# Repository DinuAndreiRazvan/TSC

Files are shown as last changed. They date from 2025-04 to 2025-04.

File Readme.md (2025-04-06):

# eBook Project - Autodesk Fusion 360 

## Images

*Complete View*
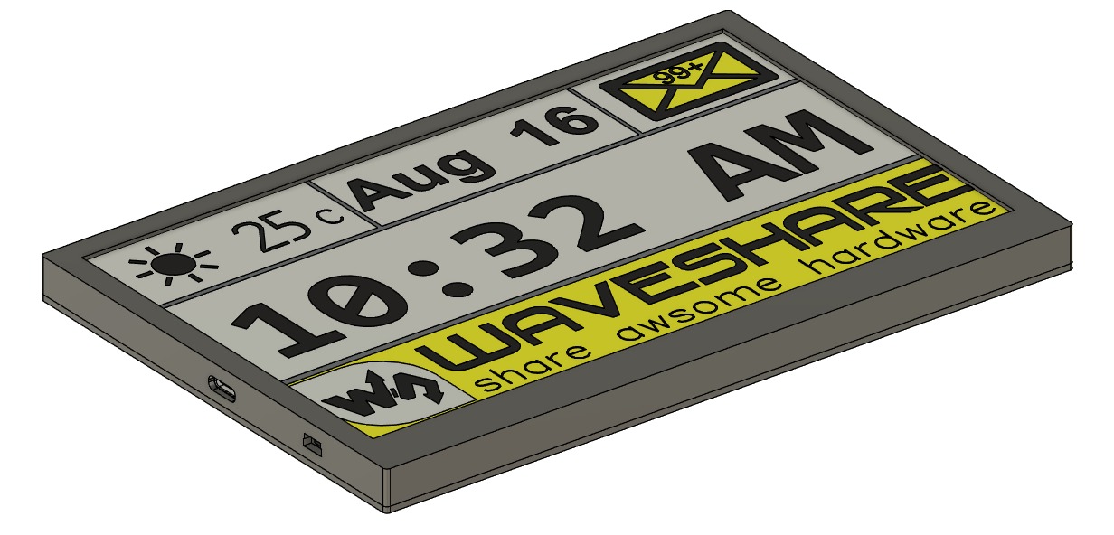
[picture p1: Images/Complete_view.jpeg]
Complete View


*Exploded View*
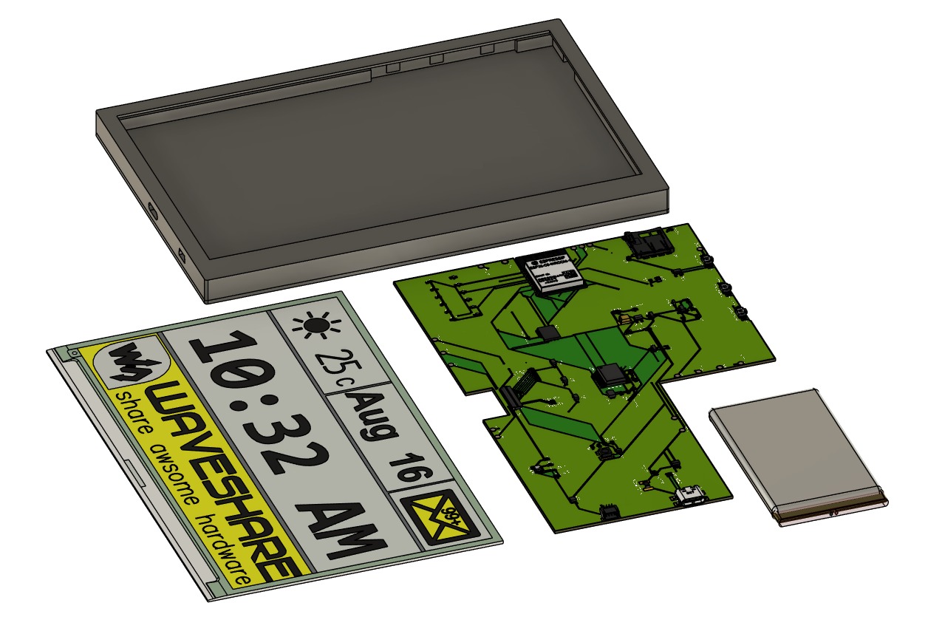
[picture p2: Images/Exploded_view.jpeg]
Exploded View


*PCB*
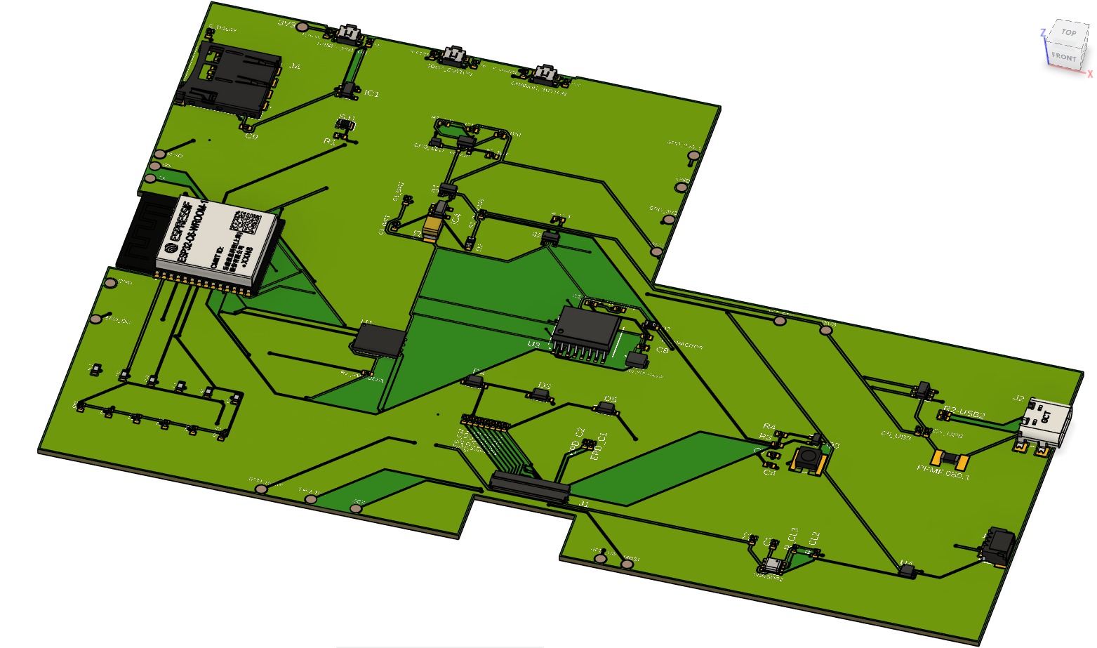
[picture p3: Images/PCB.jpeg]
PCB


## Block Diagram

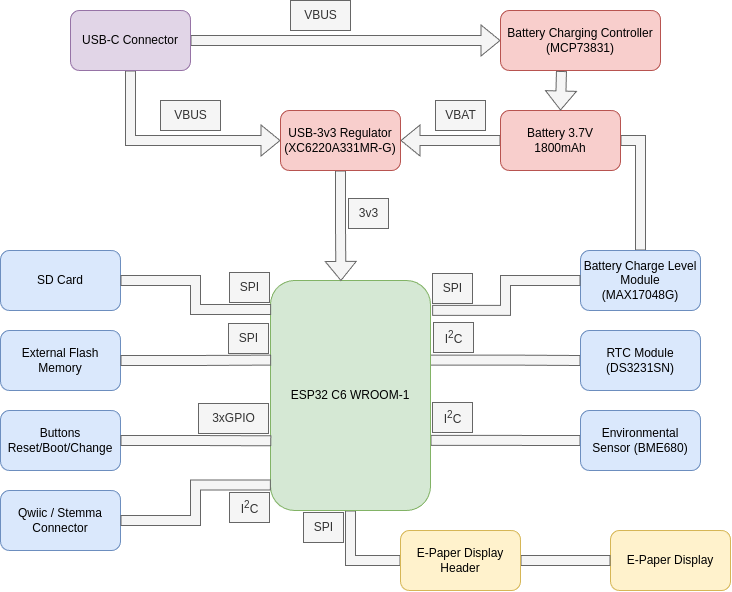
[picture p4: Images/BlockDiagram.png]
Block Diagram


## Bill of Materials

| Component | Description | Datasheet | Shop |
|---|---|---|---|
| ESP32-C6-WROOM-1-N8 | Wi-Fi, BLE, Zigbee SoC Module | [Datasheet](https://www.espressif.com/sites/default/files/documentation/esp32-c6-wroom-1_wroom-1u_datasheet_en.pdf) | [Shop](https://eu.mouser.com/ProductDetail/Espressif-Systems/ESP32-C6-WROOM-1U-N8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) |
| MCP73831 | Li-Po Battery Charging Controller | [Datasheet](https://eu.mouser.com/datasheet/2/268/MCP73831_Family_Data_Sheet_DS20001984H-3441711.pdf) | [Shop](https://eu.mouser.com/ProductDetail/Microchip-Technology/MCP73831T-2ACI-OT?qs=yUQqVecv4qvbBQBGbHx0Mw%3D%3D) |
| XC6220A331MR-G | LDO Voltage Regulator | [Datasheet](https://eu.mouser.com/datasheet/2/760/xc6220-3371556.pdf) | [Shop](https://eu.mouser.com/ProductDetail/Torex-Semiconductor/XC6220A331MR-G?qs=AsjdqWjXhJ8ZSWznL1J0gg%3D%3D) |
| BME680 | Environmental Sensor | [Datasheet](https://eu.mouser.com/datasheet/2/783/BST_BME680_DS001-1509608.pdf) | [Shop](https://eu.mouser.com/ProductDetail/Bosch-Sensortec/BME680?qs=v271MhAjFHjo0yA%2FC4OnDQ%3D%3D) |
| DS3231SN | Real-Time Clock | [Datasheet](https://eu.mouser.com/datasheet/2/609/DS3231-3421123.pdf) | [Shop](https://eu.mouser.com/ProductDetail/Analog-Devices-Maxim-Integrated/DS3231SN?qs=1eQvB6Dk1vhUlr8%2FOrV0Fw%3D%3D) |
| MAX17048G+T10 | Battery Fuel Gauge | [Datasheet](https://eu.mouser.com/datasheet/2/609/MAX17048_MAX17049-3469099.pdf) | [Shop](https://eu.mouser.com/ProductDetail/Analog-Devices-Maxim-Integrated/MAX17048G%2bT10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) |
| W25Q512JVEIQ | 512Mb Flash Memory | [Datasheet](https://eu.mouser.com/datasheet/2/949/Winbond_W25Q512JV_Datasheet-3240039.pdf) | [Shop](https://eu.mouser.com/ProductDetail/Winbond/W25Q512JVEIQ?qs=l7cgNqFNU1jw6svr3at6tA%3D%3D) |
| USB4110-GF-A | USB Type-C Connector | [Datasheet](https://eu.mouser.com/datasheet/2/837/GCT_USB4110_Product_Drawing___20k_cycles-3455479.pdf) | [Shop](https://eu.mouser.com/ProductDetail/GCT/USB4110-GF-A?qs=KUoIvG%2F9IlYiZvIXQjyJeA%3D%3D) |
| 112A-TAAR-R03 | Micro SD Card Connector | [Datasheet](https://www.attend.com.tw/data/download/file/112A-TAAR-R03_Spec.pdf) | [Shop](https://www.tme.eu/ro/details/mcc-sdmicro/conectori-pentru-cartele/attend/112a-taar-r03/) |
| SI1308EDL-T1-GE3 | N-Channel MOSFET | [Datasheet](https://www.vishay.com/docs/63399/si1308edl.pdf) | [Shop](https://eu.mouser.com/ProductDetail/Vishay-Semiconductors/SI1308EDL-T1-GE3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) |
| DMG2305UX-7 | P-Channel MOSFET | [Datasheet](https://www.diodes.com/assets/Datasheets/DMG2305UX.pdf) | [Shop](https://eu.mouser.com/ProductDetail/Diodes-Incorporated/DMG2305UX-7?qs=L1DZKBg7t5F%2FNBHrjfxC%252Bg%3D%3D) |
| USBLC6-2SC6Y | USB ESD Protection | [Datasheet](https://eu.mouser.com/datasheet/2/389/usblc6_2sc6y-1852505.pdf) | [Shop](https://eu.mouser.com/ProductDetail/STMicroelectronics/USBLC6-2SC6Y?qs=gNDSiZmRJS%2FOgDexvXkdow%3D%3D) |
| CPH3225 | 11mF Supercapacitor | [Datasheet](https://eu.mouser.com/datasheet/2/360/Seiko_Instruments_MicroBattery_E_20230330_2024Jan_-3561061.pdf) | [Shop](https://eu.mouser.com/ProductDetail/Seiko-Semiconductors/CPH3225A?qs=3etwrb1wR%252BhUOph6lAO7eg%3D%3D) |
| Waveshare Display | 7.5" E-Ink | [Datasheet](https://files.waveshare.com/upload/6/60/7.5inch_e-Paper_V2_Specification.pdf) | [Shop](https://www.waveshare.com/7.5inch-e-paper-hat.htm) |
| Cellevia Battery | Polymer Lithium-Ion | [Datasheet](https://www.tme.eu/Document/e0683d8c34e6d878124489f71bffb6ee/cel0014.pdf) | [Shop](https://www.emag.ro/acumulator-litiu-polymer-cellevia-3-7v-1800mah-accu-lp364778-c/pd/DVCNMRBBM/) | 
| MBR0530 | Schottky Diode | [Datasheet](https://www.onsemi.com/download/data-sheet/pdf/mbr0530t1-d.pdf) | [Shop](https://eu.mouser.com/ProductDetail/onsemi/MBR0530T3G?qs=3JMERSakebpEmdUS6GetdQ%3D%3D) |
| CC0402 | Capacitor | [Datasheet](https://eu.mouser.com/datasheet/2/447/upy_gphc_x5r_4v_to_50v-3461255.pdf) | [Shop](https://eu.mouser.com/ProductDetail/YAGEO/CC0402KRX5R6BB105?qs=BKNoF%2F0xMNu0TvpE6ze2Iw%3D%3D) | 
| RR0402 | Resistor | [Datasheet](https://www.vishay.com/docs/28952/mcs0402at-mct0603at-mcu0805at-mca1206at.pdf) | [Shop](https://eu.mouser.com/ProductDetail/Vishay-Beyschlag/MCS0402MD1002BE100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) |

## Hardware Functionality

### Power Management
The device can be powered in multiple ways:
- **USB Power**: Through USB-C connector (USB4110-GF-A) with ESD protection (USBLC6-2SC6Y)
- **LiPo Battery**: Charged via MCP73831 controller with status LED
- **Supercapacitor Backup**: CPH3225A for maintaining functionality during power transitions

The power path includes:
- XC6220A331MR-G LDO provides stable 3.3V to the system
- MAX17048G+T10 monitors battery capacity
- P-channel MOSFETs (DMG2305UX-7) for power path selection
- Schottky diodes (MBR0530) for reverse voltage protection

### Processing & Memory
- **ESP32-C6-WROOM-1-N8**: Main microcontroller with Wi-Fi 6, Bluetooth 5, and Zigbee 3.0 capabilities
- **W25Q512JVEIQ**: 512Mb external SPI flash memory for data storage
- **SD Card Slot**: For user data storage and expansion

### Display System
- 7.5 inch E-Paper display interfaced via SPI
- Multiple capacitors for drive stability and voltage management

### Sensors
- **BME680/BME688**: I²C environmental sensor measuring:
    - Temperature: -40 to +85°C
    - Humidity: 0-100% RH
    - Pressure: 300-1100 hPa
    - Air Quality (gas resistance)
- **DS3231SN**: Highly accurate I²C real-time clock with temperature compensation

### Connectivity
- **USB-C**: For programming, data transfer, and charging
- **Qwiic/STEMMA QT**: I²C connector for external sensors/accessories
- **SD Card**: For data storage expansion

### User Interface
- **Reset Button**: For restarting the system
- **Boot Button**: For entering bootloader mode
- **Change Button**: For user interaction with the displayed content

## ESP32-C6 Pinout Configuration

| ESP32-C6 Pin | Function | Connected Component | Interface |
|---|---|---|---|
| EN | Reset | RESET_BUTTON | Digital Input |
| GPIO 0 | INT_RTC | DS3231SN | Interrupt |
| GPIO 1 | 32 khz | DS3231SN | Clock Output |
| GPIO 2 | MISO | SPI Bus | SPI |
| GPIO 3 | E-Paper BUSY | E-Paper Display | Digital Input |
| GPIO 4 | SD Card CS | SD Card Slot | SPI |
| GPIO 5 | E-Paper DC | E-Paper Display | Digital Output |
| GPIO 6 | SCK - Clock | SPI Bus | SPI |
| GPIO 7 | MOSI | SPI Bus | SPI |
| GPIO 9 | IO/Boot | BOOT_BUTTON | Digital Input |
| GPIO 10 | E-Paper CS | E-Paper Display | SPI |
| GPIO 11 | Flash CS | W25Q512JVEIQ | SPI |
| GPIO 12 | USB_D- | USB Interface | USB |
| GPIO 13 | USB_D+ | USB Interface | USB |
| GPIO 15 | IO/Change | CHANGE_BUTTON | Digital Input |
| GPIO 16 | TX | USB-to-Serial | UART |
| GPIO 17 | RX | USB-to-Serial | UART |
| GPIO 18 | RTC Reset | DS3231SN | Digital Output |
| GPIO 19 | I2C_PW | I²C Power Control | Digital Output |
| GPIO 20 | EPD_3V3_C | E-Paper Display Power | Power Control |
| GPIO 21 | SDA | I²C Bus (BME680, RTC) | I²C |
| GPIO 22 | SCL | I²C Bus (BME680, RTC) | I²C |
| GPIO 23 | E-Paper RESET | E-Paper Display | Digital Output |

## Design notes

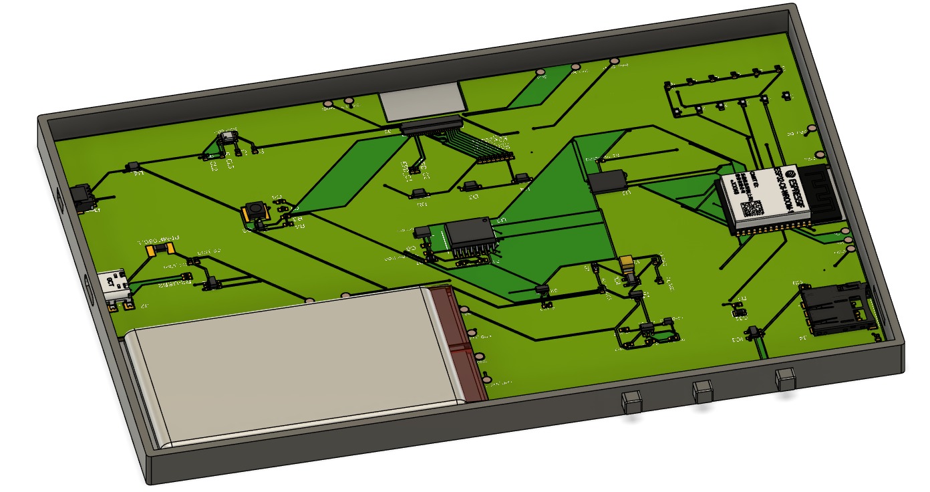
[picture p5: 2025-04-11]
Images/Open_view.jpeg

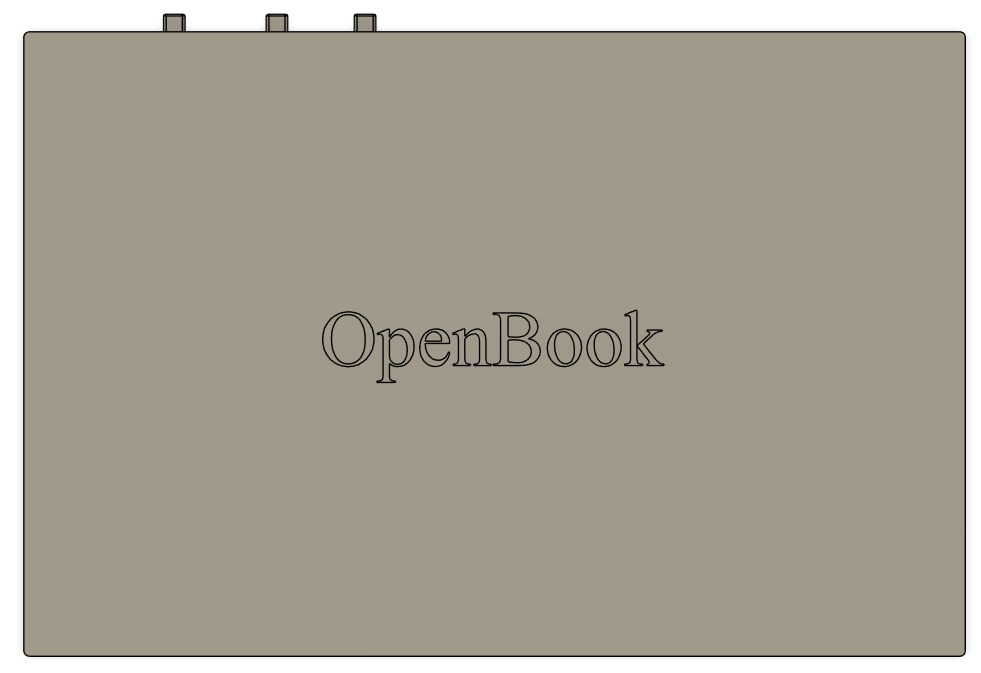
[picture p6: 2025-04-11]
Images/Back_view.jpeg

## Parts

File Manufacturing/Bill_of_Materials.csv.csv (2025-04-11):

Qty | Value | Device | Package | Parts | Description | ARROW_PART_NUMBER | ARROW_PRICE-STOCK | AVAILABILITY | CENTROID_NOT_SPECIFIED | CHECK_PRICES | COPYRIGHT | DATASHEET | DESCRIPTION | DIGIKEY_DESCRIPTION | DIGIKEY_PART_NUMBER | HEIGHT | LEAD_FREE | MANUFACTURER_NAME | MANUFACTURER_PART_NUMBER | MF | MFR_NAME | MOUSER_PART_NUMBER | MOUSER_PRICE-STOCK | MOUSER_TESTING_PART_NUMBER | MOUSER_TESTING_PRICE-STOCK | MP | MPN | PACKAGE | POPULARITY | PREFIX | PRICE | PROD_ID | PURCHASE-URL | ROHS | SNAPEDA_LINK | SPICEMODEL | SPICEPREFIX | TEMPERATURE_RANGE_HIGH | TEMPERATURE_RANGE_LOW | TP_SIGNAL_NAME | VALUE
1 |  | ADAFRUIT_LEDCHIP-LED0603 | ADAFRUIT_CHIP-LED0603 | CHG_LED | LED
1 |  | SJ | SJ | SJ1 | SMD solder JUMPER |  |  |  |  |  |  |  |  |  |  |  |  |  |  |  |  |  |  |  |  |  |  |  | 3
1 | 0.47 | ESP32_WROVER_EAGLE-LTSPICE_RR0402 | ESP32_WROVER_EAGLE-LTSPICE_R0402 | R3 | RESISTOR, European symbol |  |  |  |  |  |  |  |  |  |  |  |  |  |  |  |  |  |  |  |  |  |  |  |  |  |  |  |  |  |  | NONE | R
2 | 100k | ESP32_WROVER_EAGLE-LTSPICE_RR0402 | ESP32_WROVER_EAGLE-LTSPICE_R0402 | R1_PWRUSB, R1_PWRUSB1 | RESISTOR, European symbol |  |  |  |  |  |  |  |  |  |  |  |  |  |  |  |  |  |  |  |  |  |  |  |  |  |  |  |  |  |  | NONE | R
6 | 100nF | EAGLE-LTSPICE_CC0402 | EAGLE-LTSPICE_C0402 | C1, C2, C6, C8, C10, C_DELAY | CAPACITOR, European symbol |  |  |  |  |  |  |  |  |  |  |  |  |  |  |  |  |  |  |  |  |  |  |  |  |  |  |  |  |  |  | NONE | C
2 | 100nF | ESP32_WROVER_EAGLE-LTSPICE_CC0402 | ESP32_WROVER_EAGLE-LTSPICE_C0402 | C4_USB, C9 | CAPACITOR, European symbol |  |  |  |  |  |  |  |  |  |  |  |  |  |  |  |  |  |  |  |  |  |  |  |  |  |  |  |  |  |  | NONE | C
1 | 100uF TANT | RCL_CPOL-EUCT3528 | RCL_CT3528 | C3 | POLARIZED CAPACITOR, European symbol |  |  |  |  |  |  |  |  |  |  |  |  |  |  |  |  |  |  |  |  |  |  |  | 0 |  |  |  |  |  |  |  | C
15 | 10k | ESP32_WROVER_EAGLE-LTSPICE_RR0402 | ESP32_WROVER_EAGLE-LTSPICE_R0402 | R1_PINH1, R2_PINH1, R4, R5, R6, R7, R8, R9, R10, R_BOOT, R_CHANGE, R_CL1, R_CL2, R_CL3, R_RESET | RESISTOR, European symbol |  |  |  |  |  |  |  |  |  |  |  |  |  |  |  |  |  |  |  |  |  |  |  |  |  |  |  |  |  |  | NONE | R
1 | 10uF | EAGLE-LTSPICE_CC0402 | EAGLE-LTSPICE_C0402 | C7 | CAPACITOR, European symbol |  |  |  |  |  |  |  |  |  |  |  |  |  |  |  |  |  |  |  |  |  |  |  |  |  |  |  |  |  |  | NONE | C
1 | 112A-TAAR-R03_ATTEND | 112A-TAAR-R03_ATTEND | 112ATAARR03ATTEND | J4 | Micro SD Card Socket, Push-Push Type, Top Mount, SMT, H=1.83mm, 10u |  |  |  |  |  |  |  | Micro SD Card Socket | Push-Push Type | Top Mount | SMT | H=1.83mm | 10u |  |  | 1.9mm |  | ATTEND | 112A-TAAR-R03 ATTEND
1 | 15 | ESP32_WROVER_EAGLE-LTSPICE_RR0402 | ESP32_WROVER_EAGLE-LTSPICE_R0402 | R_CAPACITOR | RESISTOR, European symbol |  |  |  |  |  |  |  |  |  |  |  |  |  |  |  |  |  |  |  |  |  |  |  |  |  |  |  |  |  |  | NONE | R
1 | 1uF | EAGLE-LTSPICE_CC0402 | EAGLE-LTSPICE_C0402 | C5 | CAPACITOR, European symbol |  |  |  |  |  |  |  |  |  |  |  |  |  |  |  |  |  |  |  |  |  |  |  |  |  |  |  |  |  |  | NONE | C
10 | 1uF/50V | EAGLE-LTSPICE_CC0402 | EAGLE-LTSPICE_C0402 | EPD_C1, EPD_C2, EPD_C5, EPD_C6, EPD_C7, EPD_C8, EPD_C9, EPD_C10, EPD_C11, EPD_C12 | CAPACITOR, European symbol |  |  |  |  |  |  |  |  |  |  |  |  |  |  |  |  |  |  |  |  |  |  |  |  |  |  |  |  |  |  | NONE | C
1 | 2.2 | ESP32_WROVER_EAGLE-LTSPICE_RR0402 | ESP32_WROVER_EAGLE-LTSPICE_R0402 | R1 | RESISTOR, European symbol |  |  |  |  |  |  |  |  |  |  |  |  |  |  |  |  |  |  |  |  |  |  |  |  |  |  |  |  |  |  | NONE | R
1 | 200 | ESP32_WROVER_EAGLE-LTSPICE_RR0402 | ESP32_WROVER_EAGLE-LTSPICE_R0402 | R1_BAT | RESISTOR, European symbol |  |  |  |  |  |  |  |  |  |  |  |  |  |  |  |  |  |  |  |  |  |  |  |  |  |  |  |  |  |  | NONE | R
2 | 20V/4.2A/52mO/1.4W | ESP32_WROVER_SPARKFUN-DISCRETESEMI_MOSFET_PCH-DMG2305UX-7 | ESP32_WROVER_SPARKFUN-DISCRETESEMI_SOT23-3 | Q1, Q2 | P-channel MOSFETs |  |  |  |  |  |  |  |  |  |  |  |  |  |  |  |  |  |  |  |  |  |  |  |  |  |  | TRAN-14388 |  |  |  |  |  |  |  |  | 20V/4.2A/52mO/1.4W
1 | 2k | ESP32_WROVER_EAGLE-LTSPICE_RR0402 | ESP32_WROVER_EAGLE-LTSPICE_R0402 | R2_BAT | RESISTOR, European symbol |  |  |  |  |  |  |  |  |  |  |  |  |  |  |  |  |  |  |  |  |  |  |  |  |  |  |  |  |  |  | NONE | R
4 | 4.7uF | EAGLE-LTSPICE_CC0402 | EAGLE-LTSPICE_C0402 | C1_BAT, C1_BAT1, C1_BAT2, C2_BAT | CAPACITOR, European symbol |  |  |  |  |  |  |  |  |  |  |  |  |  |  |  |  |  |  |  |  |  |  |  |  |  |  |  |  |  |  | NONE | C
1 | 4.7uF | ESP32_WROVER_EAGLE-LTSPICE_CC0402 | ESP32_WROVER_EAGLE-LTSPICE_C0402 | C5_USB | CAPACITOR, European symbol |  |  |  |  |  |  |  |  |  |  |  |  |  |  |  |  |  |  |  |  |  |  |  |  |  |  |  |  |  |  | NONE | C
1 | 4.7uF/25V | EAGLE-LTSPICE_CC0402 | EAGLE-LTSPICE_C0402 | C4 | CAPACITOR, European symbol |  |  |  |  |  |  |  |  |  |  |  |  |  |  |  |  |  |  |  |  |  |  |  |  |  |  |  |  |  |  | NONE | C
2 | 5k1 | ESP32_WROVER_EAGLE-LTSPICE_RR0402 | ESP32_WROVER_EAGLE-LTSPICE_R0402 | R2-USB1, R2-USB2 | RESISTOR, European symbol |  |  |  |  |  |  |  |  |  |  |  |  |  |  |  |  |  |  |  |  |  |  |  |  |  |  |  |  |  |  | NONE | R
1 | 744043680IND_4828-WE-TPC_WRE | 744043680IND_4828-WE-TPC_WRE | IND_4828-WE-TPC_WRE | L1 |  |  |  |  |  |  | Copyright (C) 2024 Ultra Librarian. All rights reserved. |  |  |  |  |  |  |  | 744043680 |  | Wurth Electronics
1 | BD5229G-TR | BD5229G-TR | SOT95P280X125-5N | IC1 | Voltage Detector with Adjustable Delay Time: CMOS processes are utilized to develop high precision, low current consumption CMOS reset ICs that allow arbitrary setting of the delay time. The extensive lineup includes both Nch Open Drain and CMOS output types in a wide range of detection voltages (from 2.3V to 6.0V, in 0.1V steps), enabling selection of the ideal solution based on customer requirements. In addition, the entire series is of course both lead-free and RoHS-compliant. |  |  |  |  |  |  |  | Voltage Detector with Adjustable Delay Time: CMOS processes are utilized to develop high precision | low current consumption CMOS reset ICs that allow arbitrary setting of the delay time. The extensive lineup includes both Nch Open Drain and CMOS output types in a wide range of detection voltages (from 2.3V to 6.0V | in 0.1V steps) | enabling selection of the ideal solution based on customer requirements. In addition | the entire series is of course both lead-free and RoHS-compliant. |  |  | 1.25mm |  | ROHM Semiconductor | BD5229G-TR |  |  | 755-BD5229G-TR | https://www.mouser.co.uk/ProductDetail/ROHM-Semiconductor/BD5229G-TR?qs=4kLU8WoGk0vvnhrrYwdszw%3D%3D
3 | BUTTON_CUSYOMV1 | BUTTON_CUSYOMV1 | MYBUTTON | BOOT_BUTTON, CHANGE_BUTTON, RESET_BUTTON
1 | CPH3225A | CPH3225A | CAPCP3225X100N | C10_SUPERCAP | Cap 0.011F 3.3V 1210 Flat Check availability |  |  | Not in stock |  | https://www.snapeda.com/parts/CPH3225A/Seiko+Instruments/view-part/?ref=eda |  |  | 11 mF (EDLC) Supercapacitor 3.3 V 1210 (3225 Metric) - - |  |  |  |  |  |  | Seiko Instruments |  |  |  |  |  | CPH3225A |  | 1210 Seiko |  |  | None |  | https://www.snapeda.com/api/url_track_click_mouser/?unipart_id=562593&manufacturer=Seiko Instruments&part_name=CPH3225A&search_term=None |  | https://www.snapeda.com/parts/CPH3225A/Seiko+Instruments/view-part/?ref=snap
1 | DS3231SN# | DS3231SN# | SOIC127P1032X265-16N | U3 | Real Time Clock Serial 16-Pin SOIC W T/R Check availability |  |  | In Stock |  | https://www.snapeda.com/parts/DS3231SN%23/Analog+Devices/view-part/?ref=eda |  |  | Extremely Accurate I²C-Integrated RTC/TCXO/Crystal |  |  |  |  |  |  | Analog Devices |  |  |  |  |  | DS3231SN# |  | SOIC-16 Maxim |  |  | None |  | https://www.snapeda.com/api/url_track_click_mouser/?unipart_id=99048&manufacturer=Analog Devices&part_name=DS3231SN#&search_term=None |  | https://www.snapeda.com/parts/DS3231SN%23/Analog+Devices/view-part/?ref=snap
1 | ESP32-C6-WROOM-1-N8 | ESP32-C6-WROOM-1-N8 | XCVR_ESP32-C6-WROOM-1-N8 | U2 | Check availability |  |  | In Stock |  | https://www.snapeda.com/parts/ESP32-C6-WROOM-1-N8/Espressif+Systems/view-part/?ref=eda |  |  | Multiprotocol Modules ESP32-C6 module | Wi-Fi 6 in 2.4 GHz band | Bluetooth 5 | Zigbee 3.0 and Thread. ESP34-WROOM Compatible - ENGINEERING SAMPLE |  |  |  |  |  |  | Espressif Systems |  |  |  |  |  | ESP32-C6-WROOM-1-N8 |  | None |  |  | None |  |  |  | https://www.snapeda.com/parts/ESP32-C6-WROOM-1-N8/Espressif+Systems/view-part/?ref=snap
1 | ESP32C6_VARISTORCN1812 | ESP32C6_VARISTORCN1812 | ESP32C6_VARISTOR_CT/CN1812 | PFMF.050.1 | VARISTOR |  |  |  |  |  |  |  |  |  |  |  |  |  |  |  |  |  |  |  |  |  |  |  | 0
2 | ESP32_WROVER_AVX---SD0805S020S1R0_AVX_SD0805S020S1R0_0_0AVX_SD0805S020S1R0_0_0 | ESP32_WROVER_AVX---SD0805S020S1R0_AVX_SD0805S020S1R0_0_0AVX_SD0805S020S1R0_0_0 | ESP32_WROVER_AVX---SD0805S020S1R0_AVX_SD0805S020S1R0_0 | D2, D7 | Schottky Barrier Rectifier Diode |  |  |  | No |  |  | http://datasheets.avx.com/schottky.pdf |  | DIODE SCHOTTKY 20V 1A 0805 | 478-7800-1-ND |  | yes |  |  | AVX |  | 581-SD0805S020S1R0 |  |  |  |  |  | 0805 (2012 metric) |  | D |  |  |  | yes |  |  |  | +125°C | -55°C
1 | ESP32_WROVER_BME680_BME680 | ESP32_WROVER_BME680_BME680 | ESP32_WROVER_BME680_PSON80P300X300X100-8N | SENSOR2 | Integrated Environmental Unit |  |  | Unavailable |  |  |  |  | Integrated Environmental Unit |  |  |  |  |  |  | Bosch Sensortec |  |  |  |  |  | BME680 |  | LGA-8 Bosch Tools |  |  | None
1 | ESP32_WROVER_SPARKFUN-IC-POWER_MCP73831 | ESP32_WROVER_SPARKFUN-IC-POWER_MCP73831 | ESP32_WROVER_SPARKFUN-IC-POWER_SOT23-5 | MCP73831 | MCP73831T Li-Ion, Li-Pol Controller |  |  |  |  |  |  |  |  |  |  |  |  |  |  |  |  |  |  |  |  |  |  |  |  |  |  | IC-09995
1 | FH34SRJ-24S-0.5SH_99_ | FH34SRJ-24S-0.5SH_99_ | FH34SRJ24S05SH99 | J1 | (0.50mm) Surface Mount, Right Angle |  |  |  |  |  |  |  | 24 Position FFC | FPC Connector Contacts | (0.50mm) Surface Mount | Right Angle |  |  | 1.1mm |  | Hirose | FH34SRJ-24S-0.5SH(99) |  |  | 798-FH34SRJ24S05SH99 | https://www.mouser.co.uk/ProductDetail/Hirose-Connector/FH34SRJ-24S-0.5SH99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
1 | MAX17048G+T10 | MAX17048G+T10 | SON50P200X200X80-9N | U4 | Check availability |  |  | In Stock |  | https://www.snapeda.com/parts/MAX17048G+T10/Analog+Devices/view-part/?ref=eda |  |  | 3µA 1-Cell/2-Cell Fuel Gauge with ModelGauge |  |  |  |  |  |  | Analog Devices |  |  |  |  |  | MAX17048G+T10 |  | TDFN-8 Maxim |  |  | None |  | https://www.snapeda.com/api/url_track_click_mouser/?unipart_id=329239&manufacturer=Analog Devices&part_name=MAX17048G+T10&search_term=None |  | https://www.snapeda.com/parts/MAX17048G+T10/Analog+Devices/view-part/?ref=snap
3 | MBR0530 | MBR0530 | SOD3716X135N | D3, D4, D5 | ON SEMICONDUCTOR - MBR0530 - DIODE, SCHOTTKY, 0.5A, 30V, SOD-123 |  |  | In Stock |  | https://www.snapeda.com/parts/MBR0530/Onsemi/view-part/?ref=eda |  |  | Diode Schottky 30 V 500mA Surface Mount SOD-123 |  |  |  |  |  |  | ON Semiconductor |  |  |  |  |  | MBR0530 |  | SOD-123-2 ON Semiconductor |  |  | None |  | https://www.snapeda.com/api/url_track_click_mouser/?unipart_id=179458&manufacturer=ON Semiconductor&part_name=MBR0530&search_term=None |  | https://www.snapeda.com/parts/MBR0530/Onsemi/view-part/?ref=snap
6 | PGB1010603MR | PGB1010603MR | DIOC1608X36N | D6, D8, D9, D10, D11, D12 | Check availability |  |  | In Stock |  | https://www.snapeda.com/parts/PGB1010603MR/Littelfuse/view-part/?ref=eda |  |  | 150V (Typ) Clamp - Ipp Tvs Diode Surface Mount 0603 (1608 Metric) |  |  |  |  |  |  | Littelfuse Inc. |  |  |  |  |  | PGB1010603MR |  | 0603 Littelfuse Inc. |  |  | None |  | https://www.snapeda.com/api/url_track_click_mouser/?unipart_id=5659453&manufacturer=Littelfuse Inc.&part_name=PGB1010603MR&search_term=None |  | https://www.snapeda.com/parts/PGB1010603MR/Littelfuse/view-part/?ref=snap
1 | QWIIC_RIGHT_ANGLE | QWIIC_CONNECTORJS-1MM | JST04_1MM_RA | J3 | SparkFun I2C Standard Qwiic Connector |  |  |  |  |  |  |  |  |  |  |  |  |  |  |  |  |  |  |  |  |  |  |  |  |  |  | CONN-13694 |  |  |  |  |  |  |  |  | QWIIC_RIGHT_ANGLE
1 | SAMACSYS_PARTS_USB4110-GF-A | SAMACSYS_PARTS_USB4110-GF-A | SAMACSYS_PARTS_USB4110GFA | J2 | CONN USB 2.0 TYPE-C R/A SMT |  |  |  |  |  |  |  | CONN USB 2.0 TYPE-C R/A SMT |  |  | 3.26mm |  | GCT (GLOBAL CONNECTOR TECHNOLOGY) | USB4110-GF-A |  |  | 640-USB4110-GF-A | https://www.mouser.co.uk/ProductDetail/GCT/USB4110-GF-A?qs=KUoIvG%2F9IlYiZvIXQjyJeA%3D%3D
1 | SI1308EDL-T1-GE3 | SI1308EDL-T1-GE3 | SOT65P210X110-3N | Q3 | MOSFET N-Ch 30V 1.5A TrenchFET SC70 Vishay Si1308EDL-T1-GE3 N-channel MOSFET Transistor, 1.5 A, 30 V, 3-Pin SC-70 |  |  | In Stock |  | https://www.snapeda.com/parts/SI1308EDL-T1-GE3/Vishay+Siliconix/view-part/?ref=eda |  |  | Si1308EDL-T1-GE3 N-channel MOSFET Transistor | 1.5 A | 30 V | 3-Pin SC-70 | Siliconix / Vishay SI1308EDL-T1-GE3 |  |  |  |  |  |  | Vishay Siliconix |  |  |  |  |  | SI1308EDL-T1-GE3 |  | SOT-323 Vishay Semiconductor |  |  | None |  | https://www.snapeda.com/api/url_track_click_mouser/?unipart_id=274603&manufacturer=Vishay Siliconix&part_name=SI1308EDL-T1-GE3&search_term=None |  | https://www.snapeda.com/parts/SI1308EDL-T1-GE3/Vishay+Siliconix/view-part/?ref=snap
17 | TPTP20R | TPTP20R | TP20R | 3V3, EPD_3V3, EPD_3V3_C, EPD_BUSY, EPD_CS, EPD_DC, EPD_RST, GND, GND., INT_RTC, MISO, MOSI, RX, SCK, TX, VBAT, VBUS | Test pad |  |  |  |  |  |  |  |  |  |  |  |  |  |  |  |  |  |  |  |  |  |  |  | 2
1 | USBLC6-2SC6Y | USBLC6-2SC6Y | SOT95P280X145-6N | D1 | Low Cap. ESD Protection Auto SOT-23-6 STMicroelectronics USBLC6-2SC6Y, Dual Uni-Directional TVS Diode Array, 6-Pin SOT-23 |  |  | In Stock |  | https://www.snapeda.com/parts/USBLC6-2SC6Y/STMicroelectronics/view-part/?ref=eda |  |  | 17V Clamp 5A (8/20µs) Ipp Tvs Diode Surface Mount SOT-23-6 |  |  |  |  |  |  | STMicroelectronics |  |  |  |  |  | USBLC6-2SC6Y |  | SOT-23-6 STMicroelectronics |  |  | None |  |  |  | https://www.snapeda.com/parts/USBLC6-2SC6Y/STMicroelectronics/view-part/?ref=snap
1 | W25Q512JVEIQ | W25Q512JVEIQ | SON127P600X800X80-9N | U1 | Check availability |  |  | In Stock |  | https://www.snapeda.com/parts/W25Q512JVEIQ/Winbond+Electronics/view-part/?ref=eda |  |  | FLASH - NOR Memory IC 512Mb (64M x 8) SPI - Quad I/O 133 MHz 8-WSON (8x6) |  |  |  |  |  |  | Winbond Electronics |  |  |  |  |  | W25Q512JVEIQ |  | Package |  |  | None |  |  |  | https://www.snapeda.com/parts/W25Q512JVEIQ/Winbond+Electronics/view-part/?ref=snap
1 | XC6220A331MR-G | XC6220A331MR-G | SOT95P280X120-5N | IC4 | LDO Voltage Regulators |  |  |  |  |  |  |  | LDO Voltage Regulators |  |  | 1.2mm |  | Torex | XC6220A331MR-G |  |  | 865-XC6220A331MR-G | https://www.mouser.co.uk/ProductDetail/Torex-Semiconductor/XC6220A331MR-G?qs=AsjdqWjXhJ8ZSWznL1J0gg%3D%3D

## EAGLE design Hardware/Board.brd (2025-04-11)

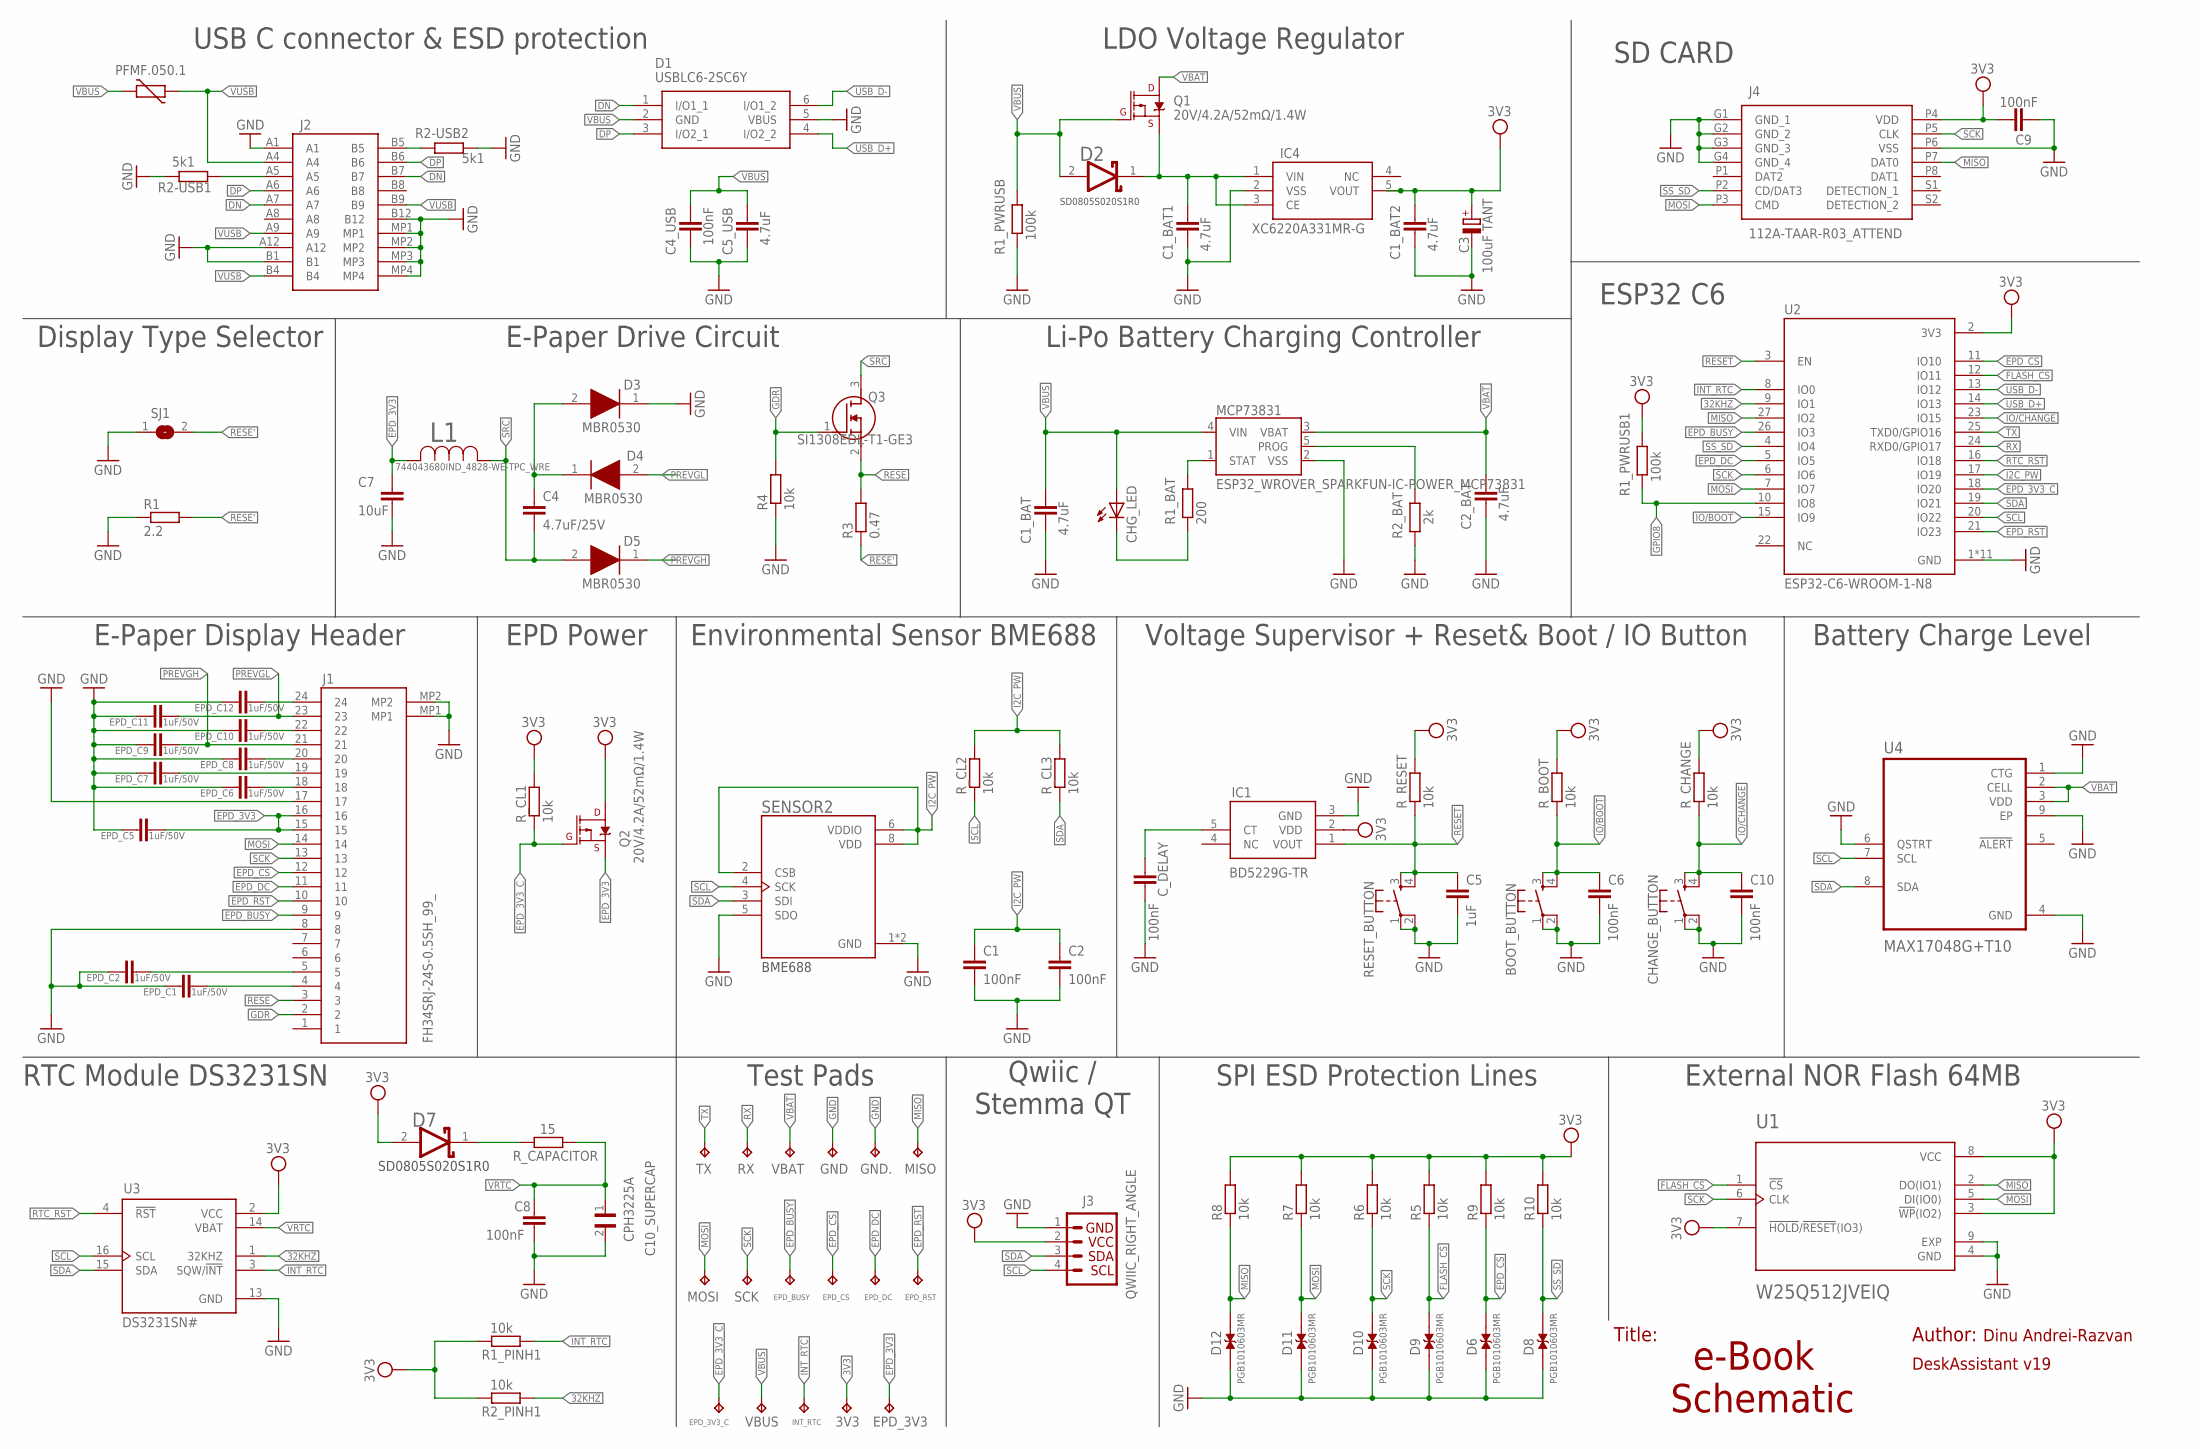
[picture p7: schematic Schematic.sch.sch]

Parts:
3V3: TPTP20R; TP20R
BOOT_BUTTON: BUTTON_CUSYOMV1; MYBUTTON
C1, C2, C6, C8, C10: 100nF; EAGLE-LTSPICE_C0402
C1_BAT, C1_BAT1, C1_BAT2, C2_BAT: 4.7uF; EAGLE-LTSPICE_C0402
C3: 100uF TANT; RCL_CT3528
C4: 4.7uF/25V; EAGLE-LTSPICE_C0402
C4_USB, C9: 100nF; ESP32_WROVER_EAGLE-LTSPICE_C0402
C5: 1uF; EAGLE-LTSPICE_C0402
C5_USB: 4.7uF; ESP32_WROVER_EAGLE-LTSPICE_C0402
C7: 10uF; EAGLE-LTSPICE_C0402
C10_SUPERCAP: CPH3225A; CAPCP3225X100N
CHANGE_BUTTON: BUTTON_CUSYOMV1; MYBUTTON
CHG_LED: ADAFRUIT_LEDCHIP-LED0603; ADAFRUIT_CHIP-LED0603
C_DELAY: 100nF; EAGLE-LTSPICE_C0402
D1: USBLC6-2SC6Y; SOT95P280X145-6N
D2, D7: ESP32_WROVER_AVX---SD0805S020S1R0_AVX_SD0805S020S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; ESP32_WROVER_AVX---SD0805S020S1R0_AVX_SD0805S020S1R0_0
D3, D4, D5: MBR0530; SOD3716X135N
D6, D8, D9, D10, D11, D12: PGB1010603MR; DIOC1608X36N
EPD_3V3, EPD_3V3_C: TPTP20R; TP20R
EPD_BUSY: TPTP20R; TP20R
EPD_C1, EPD_C2, EPD_C5, EPD_C6, EPD_C7, EPD_C8, EPD_C9, EPD_C10, EPD_C11, EPD_C12: 1uF/50V; EAGLE-LTSPICE_C0402
EPD_CS: TPTP20R; TP20R
EPD_DC: TPTP20R; TP20R
EPD_RST: TPTP20R; TP20R
GND, GND.: TPTP20R; TP20R
IC1: BD5229G-TR; SOT95P280X125-5N
IC4: XC6220A331MR-G; SOT95P280X120-5N
INT_RTC: TPTP20R; TP20R
J1: FH34SRJ-24S-0.5SH_99_; FH34SRJ24S05SH99
J2: SAMACSYS_PARTS_USB4110-GF-A; SAMACSYS_PARTS_USB4110GFA
J3: QWIIC_RIGHT_ANGLE; JST04_1MM_RA
J4: 112A-TAAR-R03_ATTEND; 112ATAARR03ATTEND
L1: 744043680IND_4828-WE-TPC_WRE; IND_4828-WE-TPC_WRE
MCP73831: ESP32_WROVER_SPARKFUN-IC-POWER_MCP73831; ESP32_WROVER_SPARKFUN-IC-POWER_SOT23-5
MISO: TPTP20R; TP20R
MOSI: TPTP20R; TP20R
PFMF.050.1: ESP32C6_VARISTORCN1812; ESP32C6_VARISTOR_CT/CN1812
Q1, Q2: 20V/4.2A/52mΩ/1.4W; ESP32_WROVER_SPARKFUN-DISCRETESEMI_SOT23-3
Q3: SI1308EDL-T1-GE3; SOT65P210X110-3N
R1: 2.2; ESP32_WROVER_EAGLE-LTSPICE_R0402
R1_BAT: 200; ESP32_WROVER_EAGLE-LTSPICE_R0402
R1_PINH1, R2_PINH1, R4, R5, R6, R7, R8, R9, R10: 10k; ESP32_WROVER_EAGLE-LTSPICE_R0402
R1_PWRUSB, R1_PWRUSB1: 100k; ESP32_WROVER_EAGLE-LTSPICE_R0402
R2-USB1, R2-USB2: 5k1; ESP32_WROVER_EAGLE-LTSPICE_R0402
R2_BAT: 2k; ESP32_WROVER_EAGLE-LTSPICE_R0402
R3: 0.47; ESP32_WROVER_EAGLE-LTSPICE_R0402
RESET_BUTTON: BUTTON_CUSYOMV1; MYBUTTON
RX: TPTP20R; TP20R
R_BOOT: 10k; ESP32_WROVER_EAGLE-LTSPICE_R0402
R_CAPACITOR: 15; ESP32_WROVER_EAGLE-LTSPICE_R0402
R_CHANGE: 10k; ESP32_WROVER_EAGLE-LTSPICE_R0402
R_CL1, R_CL2, R_CL3: 10k; ESP32_WROVER_EAGLE-LTSPICE_R0402
R_RESET: 10k; ESP32_WROVER_EAGLE-LTSPICE_R0402
SCK: TPTP20R; TP20R
SENSOR2: ESP32_WROVER_BME680_BME680; ESP32_WROVER_BME680_PSON80P300X300X100-8N
SJ1: SJ
TX: TPTP20R; TP20R
U1: W25Q512JVEIQ; SON127P600X800X80-9N
U2: ESP32-C6-WROOM-1-N8; XCVR_ESP32-C6-WROOM-1-N8
U3: DS3231SN#; SOIC127P1032X265-16N
U4: MAX17048G+T10; SON50P200X200X80-9N
VBAT: TPTP20R; TP20R
VBUS: TPTP20R; TP20R

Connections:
3V3: 3V3.TP, C1_BAT2.1, C3.+, C9.1, D7.2 (ANODE), IC1.2 (VDD), IC4.5 (VOUT), J3.2, J4.P4 (VDD), Q2.3 (D), R1_PINH1.2, R1_PWRUSB1.2, R2_PINH1.2, R5.2, R6.2, R7.2, R8.2, R9.2, R10.2, R_BOOT.2, R_CHANGE.2, R_CL1.2, R_RESET.2, U1.3 (!WP!(IO2)), U1.7 (!HOLD!/!RESET!(IO3)), U1.8 (VCC), U2.2 (3V3), U3.2 (VCC)
32KHZ: R2_PINH1.1, U2.9 (IO1), U3.1 (32KHZ)
DN: D1.1 (I/O1_1), J2.A7, J2.B7
DP: D1.3 (I/O2_1), J2.A6, J2.B6
EPD_3V3: C7.1, EPD_3V3.TP, EPD_C5.2, J1.15, J1.16, L1.2, Q2.2 (S)
EPD_3V3_C: EPD_3V3_C.TP, Q2.1 (G), R_CL1.1, U2.18 (IO20)
EPD_BUSY: EPD_BUSY.TP, J1.9, U2.26 (IO3)
EPD_CS: D6.2, EPD_CS.TP, J1.12, R9.1, U2.11 (IO10)
EPD_DC: EPD_DC.TP, J1.11, U2.5 (IO5)
EPD_RST: EPD_RST.TP, J1.10, U2.21 (IO23)
FLASH_CS: D9.2, R5.1, U1.1 (!CS), U2.12 (IO11)
GDR: J1.2, Q3.1 (G), R4.2
GND: BOOT_BUTTON.1, BOOT_BUTTON.2, C1.2, C1_BAT.2, C1_BAT1.2, C1_BAT2.2, C2.2, C2_BAT.2, C3.-, C4_USB.2, C5.2, C5_USB.2, C6.2, C7.2, C8.2, C9.2, C10.2, C10_SUPERCAP.2, CHANGE_BUTTON.1, CHANGE_BUTTON.2, C_DELAY.2, D1.5 (VBUS), D3.1 (K), D6.1, D8.1, D9.1, D10.1, D11.1, D12.1, EPD_C1.1, EPD_C2.1, EPD_C5.1, EPD_C6.1, EPD_C7.1, EPD_C8.1, EPD_C9.1, EPD_C10.1, EPD_C11.1, EPD_C12.1, GND.TP, GND..TP, IC1.3 (GND), IC4.2 (VSS), J1.8, J1.17, J1.MP1, J1.MP2, J2.A1, J2.A12, J2.B1, J2.B12, J2.MP1, J2.MP2, J2.MP3, J2.MP4, J3.1, J4.G1 (GND_1), J4.G2 (GND_2), J4.G3 (GND_3), J4.G4 (GND_4), J4.P6 (VSS), MCP73831.2 (VSS), R1.1, R1_PWRUSB.1, R2-USB1.1, R2-USB2.1, R2_BAT.1, R4.1, RESET_BUTTON.1, RESET_BUTTON.2, SENSOR2.1 (GND), SENSOR2.5 (SDO), SENSOR2.7 (GND), SJ1.1, U1.4 (GND), U1.9 (EXP), U2.1 (GND), U2.28 (GND), U2.29_1 (GND), U2.29_2 (GND), U2.29_3 (GND), U2.29_4 (GND), U2.29_5 (GND), U2.29_6 (GND), U2.29_7 (GND), U2.29_8 (GND), U2.29_9 (GND), U3.13 (GND), U4.1 (CTG), U4.4 (GND), U4.6 (QSTRT), U4.9 (EP)
GPIO8: R1_PWRUSB1.1, U2.10 (IO8)
I2C_PW: C1.1, C2.1, R_CL2.2, R_CL3.2, SENSOR2.2 (CSB), SENSOR2.6 (VDDIO), SENSOR2.8 (VDD), U2.17 (IO19)
INT_RTC: INT_RTC.TP, R1_PINH1.1, U2.8 (IO0), U3.3 (SQW/!INT)
IO/BOOT: BOOT_BUTTON.3, BOOT_BUTTON.4, C6.1, R_BOOT.1, U2.15 (IO9)
IO/CHANGE: C10.1, CHANGE_BUTTON.3, CHANGE_BUTTON.4, R_CHANGE.1, U2.23 (IO15)
MISO: D12.2, J4.P7 (DAT0), MISO.TP, R8.1, U1.2 (DO(IO1)), U2.27 (IO2)
MOSI: D11.2, J1.14, J4.P3 (CMD), MOSI.TP, R7.1, U1.5 (DI(IO0)), U2.7 (IO7)
unnamed: J2.A5, R2-USB1.2
unnamed: J2.B5, R2-USB2.2
unnamed: C1_BAT1.1, D2.1 (CATHODE), IC4.1 (VIN), IC4.3 (CE), Q1.2 (S)
unnamed: CHG_LED.C, R1_BAT.1
unnamed: MCP73831.5 (PROG), R2_BAT.2
unnamed: C4.1, D3.2 (A), D4.1 (K)
unnamed: MCP73831.1 (STAT), R1_BAT.2
unnamed: EPD_C12.2, J1.24
unnamed: C_DELAY.1, IC1.5 (CT)
unnamed: EPD_C10.2, J1.22
unnamed: EPD_C1.2, J1.4
unnamed: EPD_C2.2, J1.5
unnamed: D7.1 (CATHODE), R_CAPACITOR.2
unnamed: EPD_C8.2, J1.20
unnamed: EPD_C7.2, J1.19
unnamed: EPD_C6.2, J1.18
PREVGH: D5.1 (K), EPD_C9.2, J1.21
PREVGL: D4.2 (A), EPD_C11.2, J1.23
RESE: J1.3, Q3.2 (S), R3.2
RESE': R1.2, R3.1, SJ1.2
RESET: C5.1, IC1.1 (VOUT), RESET_BUTTON.3, RESET_BUTTON.4, R_RESET.1, U2.3 (EN)
RTC_RST: U2.16 (IO18), U3.4 (!RST)
RX: RX.TP, U2.24 (RXD0/GPIO17)
SCK: D10.2, J1.13, J4.P5 (CLK), R6.1, SCK.TP, U1.6 (CLK), U2.6 (IO6)
SCL: J3.4, R_CL2.1, SENSOR2.4 (SCK), U2.20 (IO22), U3.16 (SCL), U4.7 (SCL)
SDA: J3.3, R_CL3.1, SENSOR2.3 (SDI), U2.19 (IO21), U3.15 (SDA), U4.8 (SDA)
SRC: C4.2, D5.2 (A), L1.1, Q3.3 (D)
SS_SD: D8.2, J4.P2 (CD/DAT3), R10.1, U2.4 (IO4)
TX: TX.TP, U2.25 (TXD0/GPIO16)
USB_D+: D1.4 (I/O2_2), U2.14 (IO13)
USB_D-: D1.6 (I/O1_2), U2.13 (IO12)
VBAT: C2_BAT.1, MCP73831.3 (VBAT), Q1.3 (D), U4.2 (CELL), U4.3 (VDD), VBAT.TP
VBUS: C1_BAT.1, C4_USB.1, C5_USB.1, CHG_LED.A, D1.2 (GND), D2.2 (ANODE), MCP73831.4 (VIN), PFMF.050.1.2, Q1.1 (G), R1_PWRUSB.2, VBUS.TP
VRTC: C8.1, C10_SUPERCAP.1, R_CAPACITOR.1, U3.14 (VBAT)
VUSB: J2.A4, J2.A9, J2.B4, J2.B9, PFMF.050.1.1

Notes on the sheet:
e-Book Schematic
Dinu Andrei-Razvan
Author:
Title:
DeskAssistant v19
USB C connector & ESD protection
LDO Voltage Regulator
SD0805S020S1R0
SD CARD
ESP32 C6
Display Type Selector
E-Paper Drive Circuit
Li-Po Battery Charging Controller
E-Paper Display Header
EPD Power
Environmental Sensor BME688
Voltage Supervisor + Reset& Boot / IO Button
Battery Charge Level
BME688
RTC Module DS3231SN
Test Pads
Qwiic / Stemma QT
SPI ESD Protection Lines
External NOR Flash 64MB

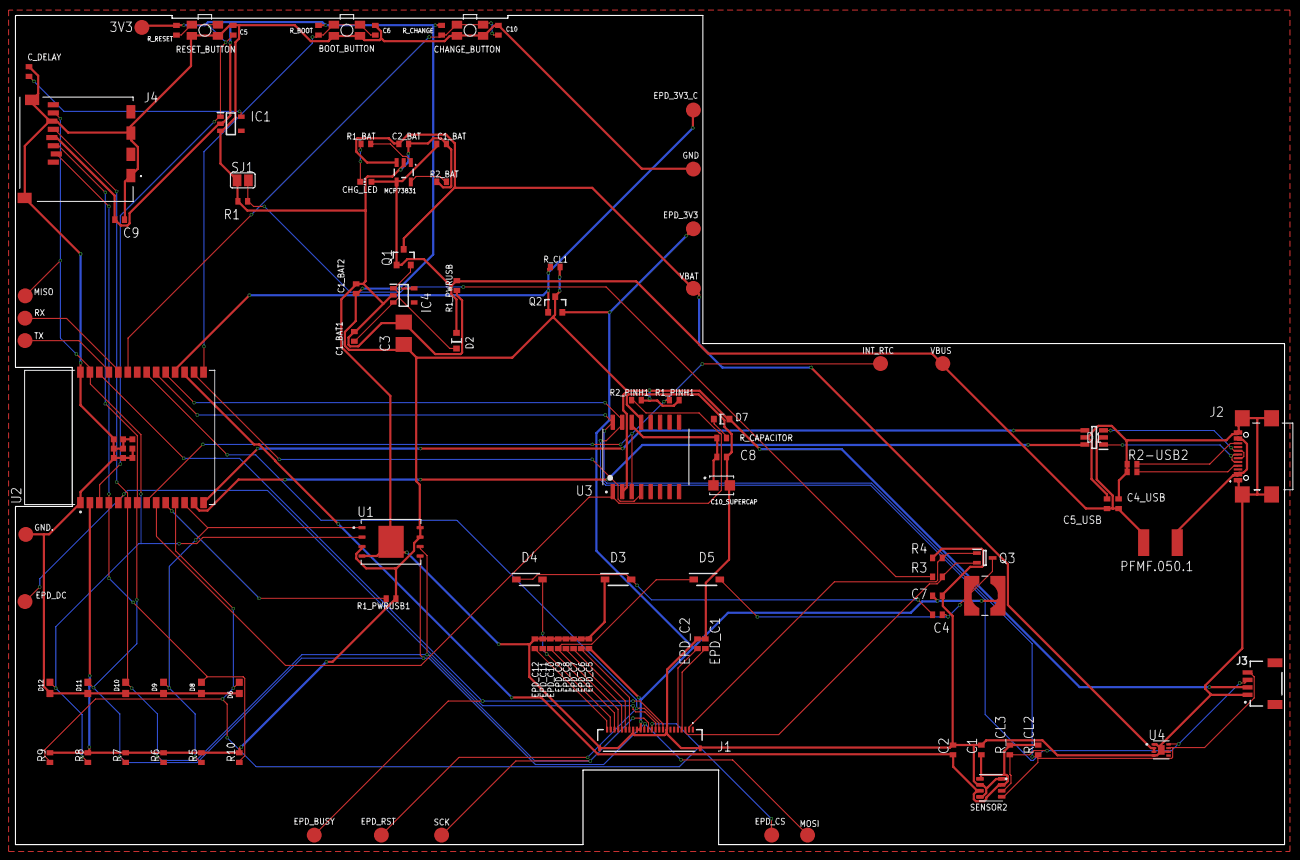
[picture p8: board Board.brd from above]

Board: 2 copper layers, 170.2 x 111.2 mm, 103 parts (0 on the bottom side), 55 nets.

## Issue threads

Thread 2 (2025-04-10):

Eliminare valori din PCB

cristiandeda, 2025-04-10:
Pe PCB nu trebuie sa apara valorile componentelor.
Majoritatea valorilor au fost eliminate, insa au fost omise valorile pentru R_BOOT, R_CHANGE, R_RESET, C5, C6, C10.

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

Closed 2025-04-11.

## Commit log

2025-03-22 completed half of the Schematics
    [Schematic.sch]
2025-04-06 removed old files
    [Schematic.sch]
2025-04-11 Solved 3D models issues, named the Test Pads accordingly and and removed component values from the PCB
    [Bill of Materials.csv, Bill_of_Materials.csv.csv, Board.brd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]

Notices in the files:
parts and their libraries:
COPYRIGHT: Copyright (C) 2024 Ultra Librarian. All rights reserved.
